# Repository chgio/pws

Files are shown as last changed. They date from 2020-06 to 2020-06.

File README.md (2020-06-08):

# PWS: Personal Weather Station software

##### COMPLETE HARDWARE-SOFTWARE-ASSEMBLY TUTORIAL ON [INSTRUCTABLES](https://www.instructables.com/id/Particle-Photon-IoT-Personal-Weather-Station)

##### SEE THE LIVE DATA PUBLISHED BY THIS CODE ON:
* [ThingSpeak](https://thingspeak.com/channels/920701)
* [WeatherUnderground](https://www.wunderground.com/dashboard/pws/IGENOA2776)
* [WeatherCloud](https://app.weathercloud.net/d0746983513#profile)

The PWS deployed
###### IMAGES ARE [CC BY 2.0](https://creativecommons.org/licenses/by/2.0)

## Hardware

Component                                           |Image                              | Store Link            | Documentation
---                                                 | ---                               | ---                   | ---
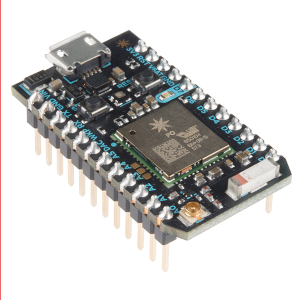
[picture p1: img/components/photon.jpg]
Photon
Particle Photon                                     |                      | [Particle Store][1b]  | [SparkFun Development Guide](https://learn.sparkfun.com/tutorials/photon-development-guide)
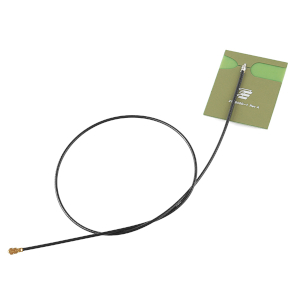
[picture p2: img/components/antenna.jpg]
Antenna
\[OPTIONAL\] 2.4GHz u.FL Antenna                    |                     | [SparkFun][2b]        | [SparkFun Hookup Guide](https://learn.sparkfun.com/tutorials/three-quick-tips-about-using-ufl)
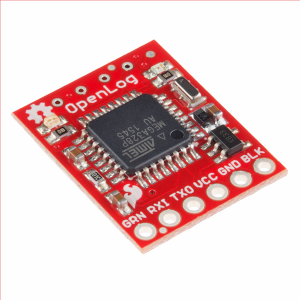
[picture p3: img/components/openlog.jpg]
OpenLog
SparkFun OpenLog                                    |                     | [SparkFun][3b]        | [SparkFun Hookup Guide](https://learn.sparkfun.com/tutorials/openlog-hookup-guide)
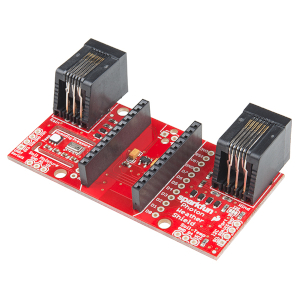
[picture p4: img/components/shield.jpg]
Weather Shield
SparkFun Photon Weather Shield                      |              | [SparkFun][4b]        | [SparkFun Hookup Guide](https://learn.sparkfun.com/tutorials/photon-weather-shield-hookup-guide-v11)
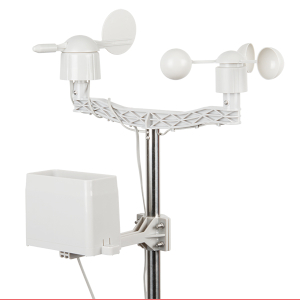
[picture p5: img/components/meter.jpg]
Weather Meters
SparkFun Weather Meters                             |              | [SparkFun][5b]        | [SparkFun Hookup Guide](https://learn.sparkfun.com/tutorials/weather-meter-hookup-guide)
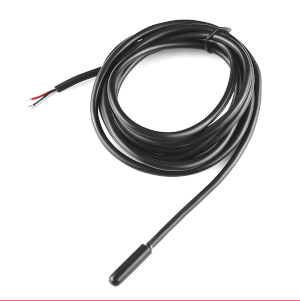
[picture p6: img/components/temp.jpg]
Soil Temperature Sensor
Dallas DS18B20 Waterproof Temperature Sensor        |     | [SparkFun][6b]        | [Example code by SparkFun on GitHub](https://github.com/sparkfun/simple_sketches/tree/master/DS18B20)
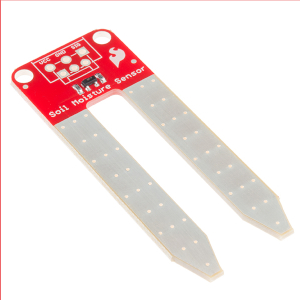
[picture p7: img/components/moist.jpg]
Soil Moisture Sensor
SparkFun Soil Moisture Sensor                       |        | [SparkFun][7b]        | [SparkFun Hookup Guide](https://learn.sparkfun.com/tutorials/soil-moisture-sensor-hookup-guide)
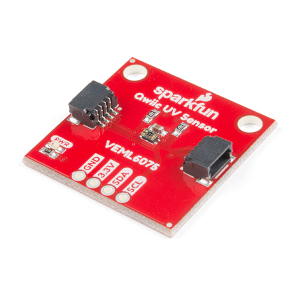
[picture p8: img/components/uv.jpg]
UV Sensor
SparkFun Qwiic VEML6075 UV Light Sensor Breakout    |                   | [SparkFun][8b]        | [SparkFun Hookup Guide](https://learn.sparkfun.com/tutorials/qwiic-uv-sensor-veml6075-hookup-guide)
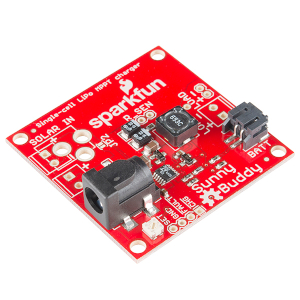
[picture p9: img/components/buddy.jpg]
Sunny Buddy
SparkFun Sunny Buddy                                |                 | [SparkFun][9b]        | [SparkFun Hookup Guide](https://learn.sparkfun.com/tutorials/qwiic-uv-sensor-veml6075-hookup-guide)
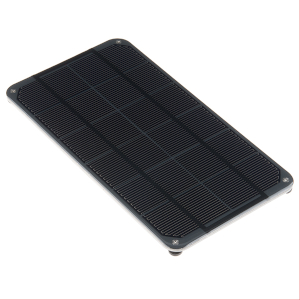
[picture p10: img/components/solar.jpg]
Solar Panel
3.5W solar panel                                    |                | [SparkFun][10b]       | --
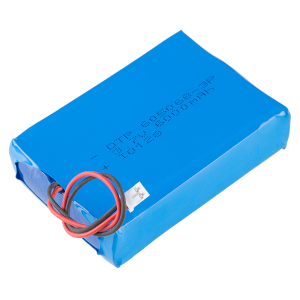
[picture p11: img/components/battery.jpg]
Li-Ion Battery
6Ah Li-Ion battery                                  |             | [SparkFun][11b]       | --
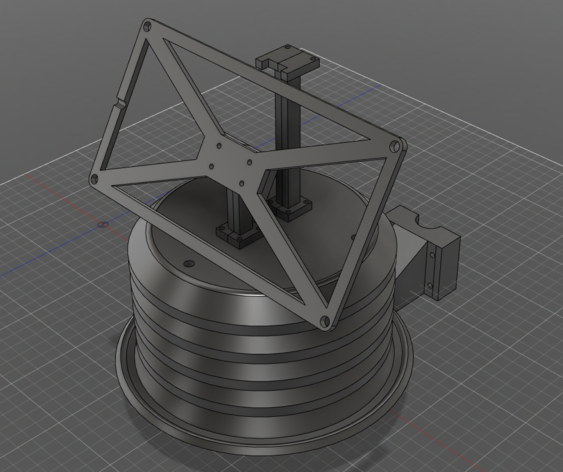
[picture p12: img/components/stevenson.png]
Stevenson Screen
Custom 3D Modelled Stevenson Screen                 |           | [Thingiverse][12b]    | --

[1a]:   
[1b]:   <https://store.particle.io/products/photon>
[2a]:   
[2b]:   <https://www.sparkfun.com/products/11320>   
[3a]:   
[3b]:   <https://www.sparkfun.com/products/>
[4a]:   
[4b]:   <https://www.sparkfun.com/products/13674>
[5a]:   
[5b]:   <https://www.sparkfun.com/products/15901>
[6a]:   
[6b]:   <https://www.sparkfun.com/products/11050>
[7a]:   
[7b]:   <https://www.sparkfun.com/products/13322>
[8a]:   
[8b]:   <https://www.sparkfun.com/products/15089>
[9a]:   
[9b]:   <https://www.sparkfun.com/products/12885>
[10a]:  
[10b]:  <https://www.sparkfun.com/products/13782>
[11a]:  
[11b]:  <https://www.sparkfun.com/products/13856>
[12a]:  
[12b]:  <https://www.thingiverse.com/thing:4435632>

## Setup

### Installation

Just clone or fork this repository from <https://github.com/ciakkig/pws>, and that's it.

#### Dependencies

Library                         | Download
---                             | ---
SparkFun Photon Weather Shield  | [GitHub][11]
OneWire                         | [GitHub][12]
Dallas DS18B20                  | [GitHub][13]
SparkFun VEML6075               | [GitHub][14]
ThingSpeak for Particle         | [GitHub][15]

[11]:   <https://github.com/sparkfun/SparkFun_Photon_Weather_Shield_Particle_Library>
[12]:   <https://github.com/particle-iot/OneWireLibrary>
[13]:   <https://github.com/particle-iot/SparkCoreDallasTemperature>
[14]:   <https://github.com/sparkfun/SparkFun_VEML6075_Arduino_Library>
[15]:   <https://github.com/mathworks/thingspeak-particle>

However, all required libraries are already included in the `lib` directory.

Additionally, this project was made using [Particle Workbench](https://www.particle.io/workbench) in [Visual Studio Code](https://code.visualstudio.com), and while not strictly necessary, using that is warmly recommended.

Otherwise, the code has also been styled (tabbed with 3 spaces) to be consistent with the [Particle Build](https://build.particle.io) cloud IDE, if that's more your thing.

### Registration

#### ThingSpeak

Set up a new channel on ThingSpeak [here](https://thingspeak.com/channels/new), entering your coordinates and elevation, and setting the first 7 fields to the following:
1. Temperature
2. Humidity
3. Pressure
4. UV Index
5. Rain Rate
6. Wind Speed
7. Wind Direction

Then, visit the channel's **API Keys** section and record your credentials to the `tsID` and `tsAPI` variables in the `credentials.h` file.

#### WeatherUnderground

Set up a personal weather station on WeatherUnderground [here](https://www.wunderground.com/member/devices/new), selecting "other" as hardware.     
You'll have to enter the station's location again, then record your credentials from the **Manage Devices** page to the `wuID` and `wuPASS` varaiables in the `credentials.h` file.

#### WeatherCloud

Set up a personal weather station on WeatherCloud [here](https://app.weathercloud.net/device/create), selecting "other" as model.   
Once again, you'll have to enter the station's location, but you'll be required to contact [WeatherCloud Support](mailto:support@weathercloud.net) to register your device to the API and get the necessary credentials -- but fear not, they don't have any particular requirements you need to satisfy.
You can then record your credentials to the `wcID`, `wcKEY` and `wcAPI`  variables in the `credentials.h` file.

For all the credentials mentioned in this section, feel free to use `templates/calibration_template.h` as a template, but don't forget to copy, rename and mention your file in your `.gitignore` if you're planning on redistributing the code to keep your credentials for yourself!

### Calibration

Calibrating sensors is always good practice.
However, the majority of the involved sensors already come factory-calibrated, and calibration methods at the intersection of reliability and affordability are basically non-existent.
Of course, you're free to calibrate as many sensors as you want -- just throw in some more `map()` functions -- but please let me know if you manage to find a good way.

As a requirement, however, you'll only have to run calibration on the sensor that needs it the most: the soil moisture sensor.      
To do that, as shown in [SparkFun's Hookup Guide](https://learn.sparkfun.com/tutorials/soil-moisture-sensor-hookup-guide#calibration), put it about three-quarters of its way inside the soil you want to calibrate it for, in a completely dry condition, and record this first raw reading to the `smCal0` variable.
Then, wet the soil as much as you can, until it's saturated with water, and record this second raw reading to the `smCal100` variable.  
Don't worry if the two values happen to be quite close: I had a difference of about **300** -- **9%** of my maximum value, and a mere tenth of the difference between my minimum value and the actual 0 recorded in air.

Another element that requires calibration is the Sunny Buddy: while not a sensor, its MPPT (Maximum Power Point Transfer) design needs to be calibrated to that point of maximum power transfer.    
To do that, as once again shown in [SparkFun's Hookup Guide](https://learn.sparkfun.com/tutorials/sunny-buddy-solar-charger-v13-hookup-guide), connect it to your solar panel on a sunny day, measure the voltage across the `SET` and `GND` pads, and tweak the nearby potentiometer with a screwdriver until that voltage is about **3V.**

## Usage

### Compiling & Flashing

#### Local

* Local compile the project through the Workbench shortcut
* Flash the compiled project over-the-wire through the Workbench shortcut

#### Cloud

* Cloud compile the project with `particle compile photon`
* Flash the compiled project over-the-air with `particle flash pws pws.bin`

I usually prefer to compile locally for more reliability and control over the code, then flash it over the air for a seamless update from wherever I happen to be.

### Interaction

The [Particle Cloud API](https://docs.particle.io/reference/device-cloud/api) provides a number of useful tools to interface with the Photon through [Particle's CLI](https://docs.particle.io/reference/developer-tools/cli/).     
Mainly, the use of [Particle Variables](https://docs.particle.io/reference/device-os/firmware/photon/#particle-variable), [Particle Functions](https://docs.particle.io/reference/device-os/firmware/photon/#particle-function) and [Particle Events](https://docs.particle.io/reference/device-os/firmware/photon/#particle-publish).

You can `get` a variable's value by issuing:    
```particle get var```      
For example, to get the `soilMoisture` variable:    
```particle get soilMoisture```

You can also `call` a function with:    
```particle call device function argument```    
For example, to call the `setSleepAt0` function with argument `0` on your device `pws`:     
```particle call pws setSleepAt0 0```

Here's the full list of all variables and functions (with their syntax) exposed through the Particle Cloud API:

Variable            | Unit
---                 | ---
`temperature`       | °C
`humidity`          | Pa
`pressure`          | %
`soilTemperature`   | °C
`soilMoisture`      | %
`uv`                | -- (index)
`rain`              | mm/min
`windSpeed`         | km/h
`windDirection`     | °N

Function                    | Arguments                                 | Usage                                                                                                                                                                 | Returns
---                         | ---                                       | ---                                                               | ---
`gotoSleepNow`              | `seconds`: > 0 / none for default         | Sends the Photon into deep sleep immediately for the specified `seconds`. If no value is specified, the code-defined default (currently 300) is used.                     | Nothing, as the Photon will be fast asleep.
`setSleepAt0`               | `flag`: 0 ~ 1                             | Overrides the flag that determines whether the Photon enters deep sleep or stays awake at the end of the loop.                                                            | 2-digit integer: *`ON`*, made up of the *O*ld flag and *N*ew flag.
`setSampleSeconds`          | `seconds`: 1 ~ 300                        | Overrides the value that determines how long the Photon samples the sensors for. If no value is specified, the code-defined default (currently 60) is used as a reset.    | 6-digit integer: *`OLDNEW`*, made up of *OLD* time and *NEW* time. `-1` in case of invalid arguments.
`getWeather`                | `seconds`: 1 ~ 300 / none for default     | Polls all sensors for the current weather, sampling in loop for the specified `seconds`. If no value is specified, the code-defined default (currently 60) is used.       | 8-digit integer: *`TEHUPRES`*, made up of *TE*mperature, *HU*midity and *PRES*sure. `-1` in case of invalid arguments.
`printData`                 | --                                        | Prints the weather data over USB Serial to a PC.                                                                                                                          | `1` in case of success, `-1` in case of failed Serial connection.
`logData`                   | --                                        | Logs the weather data over RX-TX Serial to the OpenLog.                                                                                                                   | `1` in case of success, `-1` in case of failed Serial connection.
`publishData`               | --                                        | Publishes the weather data to the Particle Cloud as private Events.                                                                                                       | `1` in case of success, nothing or error in case of failed Cloud connection.
`publishThingSpeak`         | --                                        | Publishes the weather data to [ThingSpeak](https://thingspeak.com).                                                                                                       | `1` in case of success, nothing or error in case of failed Internet connection.
`publishWeatherUnderground` | --                                        | Publishes the weather data to [WeatherUnderground](https://weatherunderground.com).                                                                                       | `1` in case of success, nothing or error in case of failed Internet connection.
`publishWeatherCloud`       | --                                        | Publishes the weather data to [WeatherCloud](https://weathercloud.net).                                                                                                   | `1` in case of success, nothing or error in case of failed Internet connection.

## Operating Principles

This program focuses on robustness, debugability and power efficiency on remote deployment, while slightly overlooking the already relatively limited precision introduced by the general-purpose sensors on board. Rather, this is expected to be achieved through a bigger set of data, both through a long, frequent and constant gathering and by averaging a number of samples to measure such data.

By default, the weather station will:
* wake up at every **--:-5** minute (i.e. 10:05, 10:15, 10:25, etc.)
* take measurements for each quantity
* do the necessary computations on the measurements
* post the data to the Particle Cloud and to the various weather network websites
* send its sensors to sleep to lower power consumption
* stand by for the next 4-5 minutes to offer a practical window for troubleshooting
* enter deep sleep at every **--:-0** minute (i.e. 10:10, 10:20, 10:30, etc.)
* repeat

However, this default cycle can be easily tailored to any particular need for troubleshooting or power saving using the interfaces mentioned above.

## License

**Copyright (C) 2020 Giorgio Ciacchella**

This program is free software: you can redistribute it and/or modify it under the terms of the GNU General Public License as published by the Free Software Foundation, either version 3 of the License, or (at your option) any later version.

This program is distributed in the hope that it will be useful, but WITHOUT ANY WARRANTY; without even the implied warranty of MERCHANTABILITY or FITNESS FOR A PARTICULAR PURPOSE.

See the GNU General Public License at `COPYING` or <https://www.gnu.org/licenses/#GPL> for more details.

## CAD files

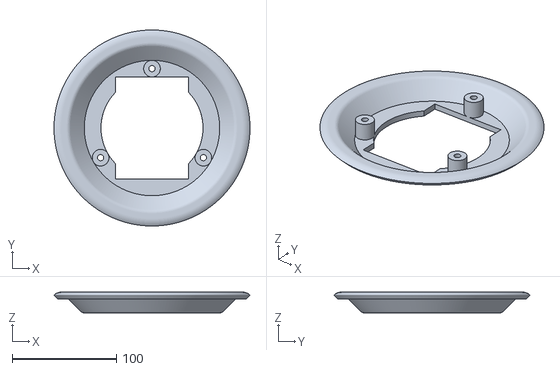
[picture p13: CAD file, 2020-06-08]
stl/screen1.stl
188.3 x 188.3 x 20.0

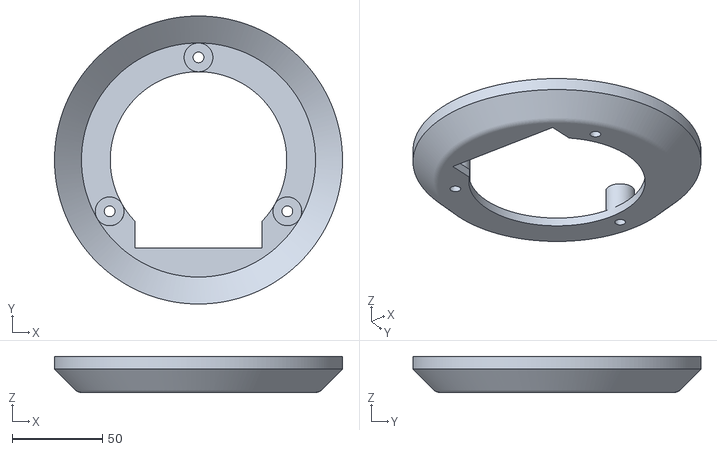
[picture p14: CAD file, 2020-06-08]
stl/screen2.stl
160.0 x 160.0 x 20.0

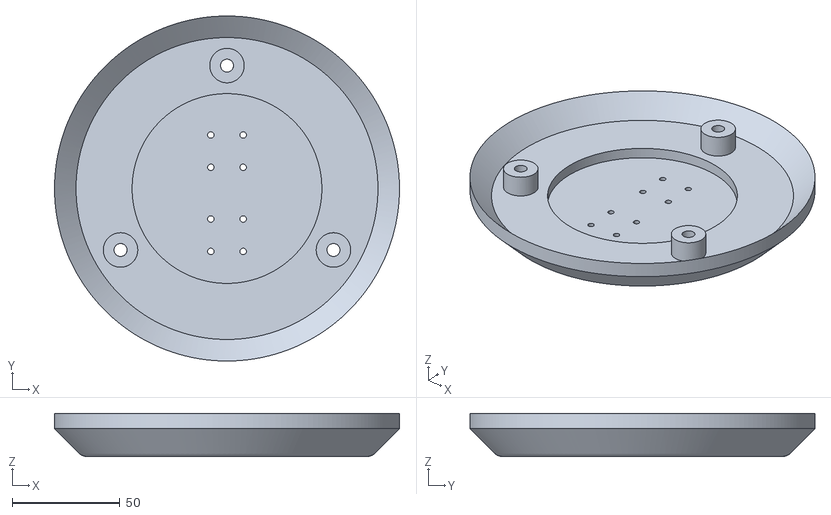
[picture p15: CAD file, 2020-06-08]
stl/screen5.stl
160.0 x 160.0 x 20.0

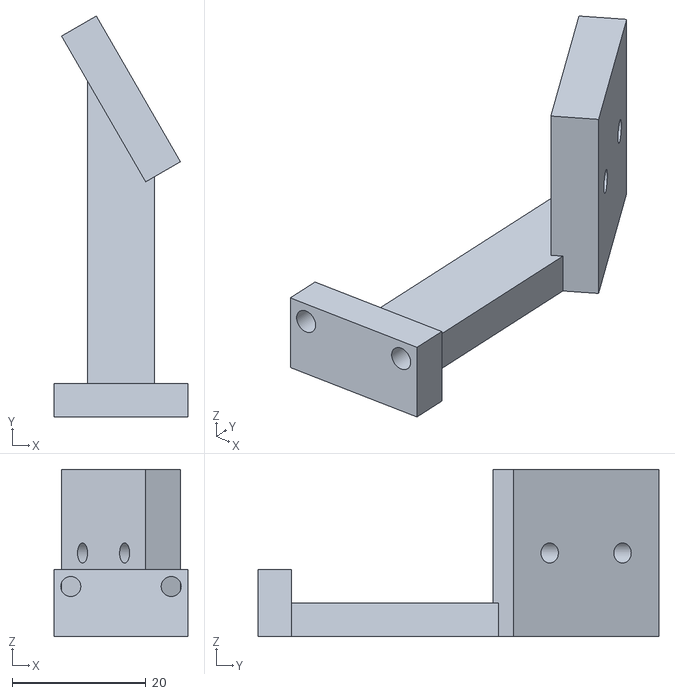
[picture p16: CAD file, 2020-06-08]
stl/solarPanelHolderLeft.stl
20.0 x 59.9 x 25.0

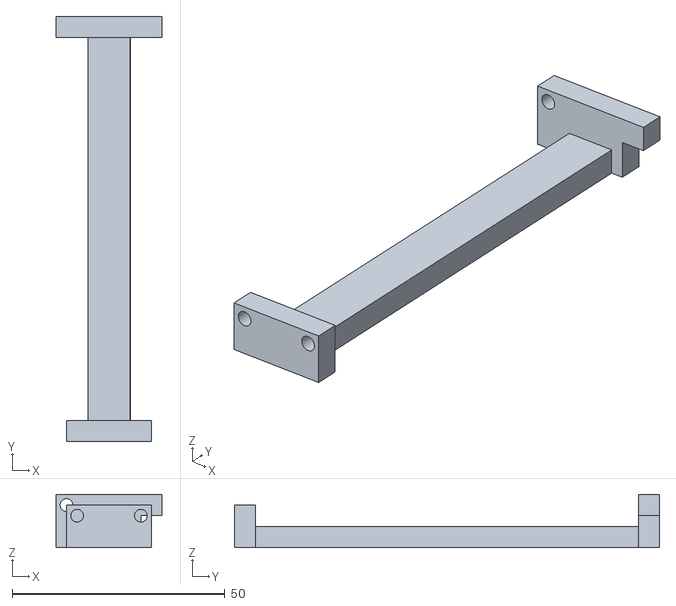
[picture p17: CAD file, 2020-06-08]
stl/uvHolderLeft.stl
25.0 x 100.0 x 12.5

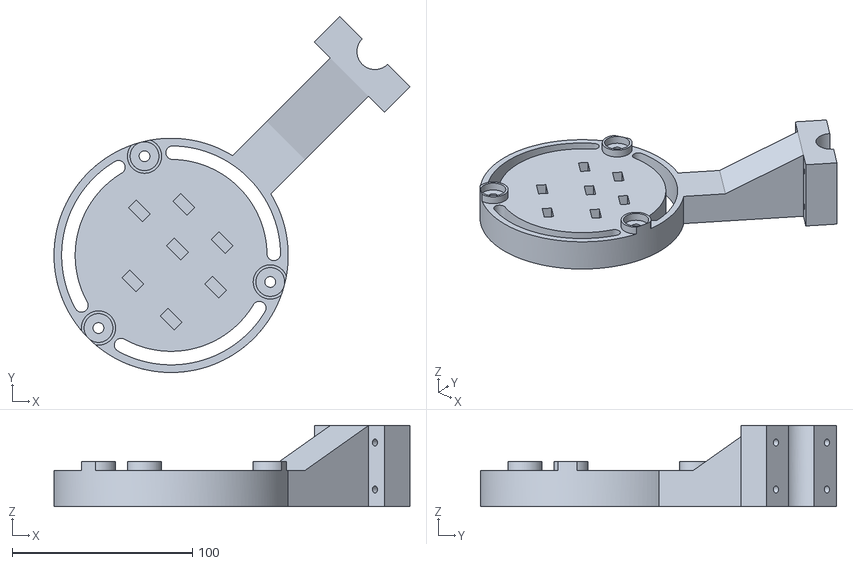
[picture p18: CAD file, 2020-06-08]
stl/basePiece.stl
197.6 x 197.6 x 45.0

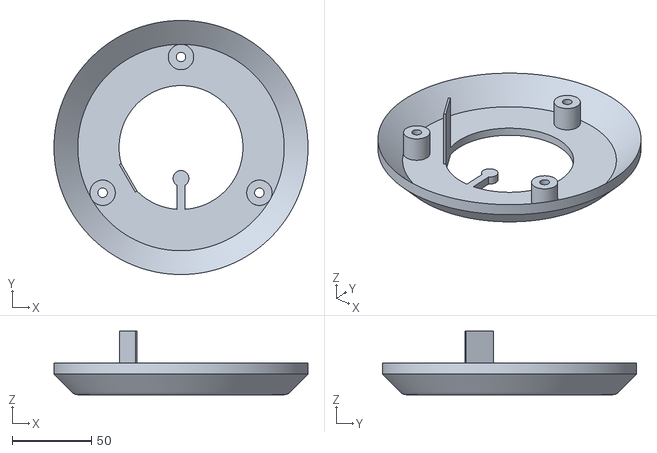
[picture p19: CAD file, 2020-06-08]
stl/screen3.stl
160.0 x 160.0 x 40.0

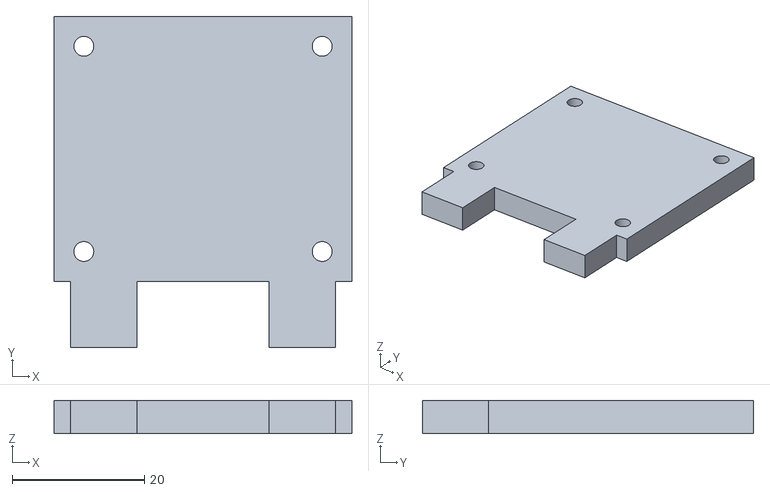
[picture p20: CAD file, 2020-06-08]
stl/shieldPiece.stl
45.0 x 50.0 x 5.00

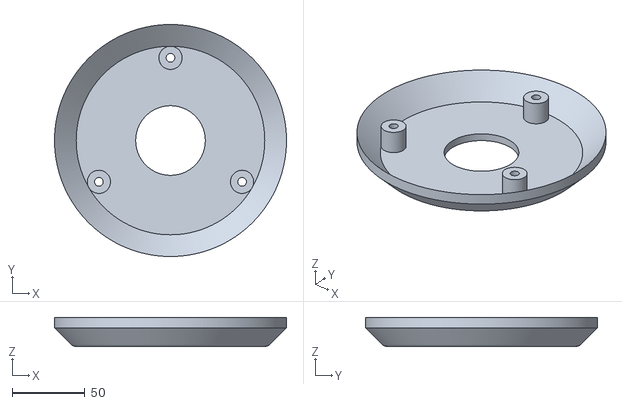
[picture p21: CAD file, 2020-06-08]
stl/screen4.stl
160.0 x 160.0 x 20.0

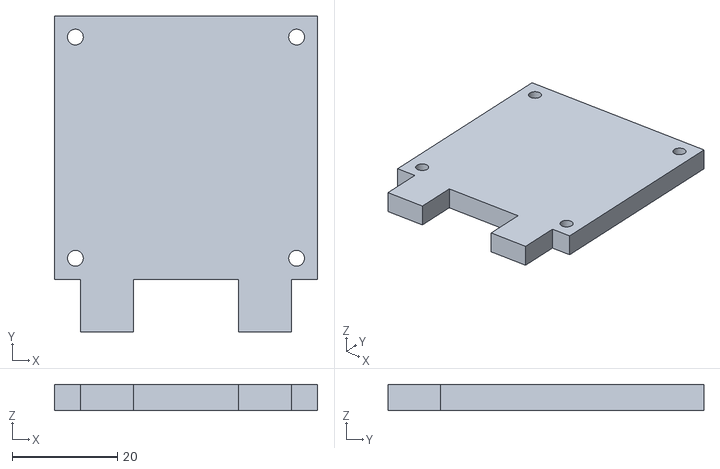
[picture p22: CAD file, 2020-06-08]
stl/sunPiece.stl
50.0 x 60.0 x 5.00

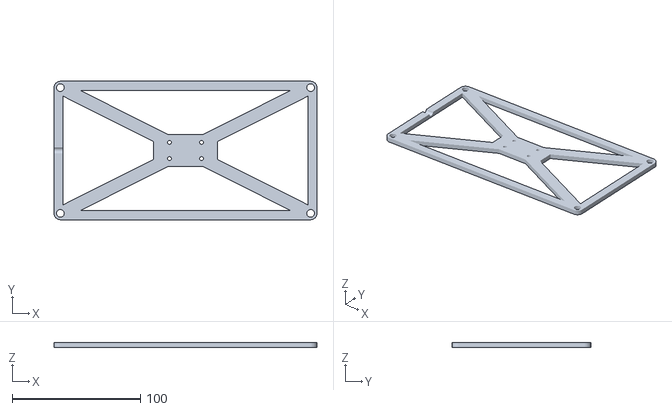
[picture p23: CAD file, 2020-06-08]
stl/solarPanelRack.stl
205.0 x 108.0 x 4.00

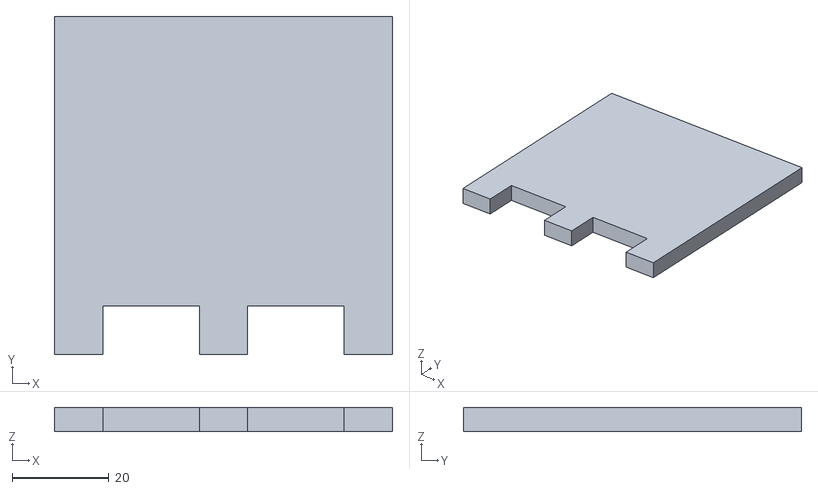
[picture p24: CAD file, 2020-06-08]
stl/batteryPiece.stl
70.0 x 70.0 x 5.00

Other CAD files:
stl/solarPanelHolderRight.stl
stl/uvHolderRight.stl

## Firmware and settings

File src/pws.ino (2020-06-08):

/*

* pws.ino         [Particle-flavoured C++]
   full version: implements all sensors and meters
   check the "simplified" git branch for the simplified version
   only implementing the Photon Weather Shield


* Description:    Particle Photon Personal Weather Station software
                  dedicated to collecting, processing and uploading the data


* Author:         Giorgio Ciacchella (https://github.com/ciakkig)


* License:        GNU GPLv3 license
   Copyright (C) 2020 Giorgio Ciacchella

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

* Hardware:
   Particle Photon                                    https://store.particle.io/products/photon
   [OPTIONAL] 2.4GHz u.FL antenna                     https://www.sparkfun.com/products/11320
   SparkFun OpenLog                                   https://www.sparkfun.com/products/13712

   SparkFun Photon Weather Shield                     https://www.sparkfun.com/products/13674
   SparkFun Weather Meters                            https://www.sparkfun.com/products/15901
   Dallas DS18B20 Waterproof Temperature Sensor       https://www.sparkfun.com/products/11050
   SparkFun Soil Moisture Sensor                      https://www.sparkfun.com/products/13322
   SparkFun Qwiic VEML6075 UV Light Sensor            https://www.sparkfun.com/products/15089

   3.5W solar panel                                   https://www.sparkfun.com/products/13782
   SparkFun Sunny Buddy                               https://www.sparkfun.com/products/12885
   Custom 3D Modelled Stevenson Screen                https://www.thingiverse.com/thing:4435632


* Creation:       04/2017
   Latest Update: 06/2020


*/


#include <math.h>

#include <SparkFun_Photon_Weather_Shield_Library.h>
#include <OneWire.h>
#include <spark-dallas-temperature.h>
#include <SparkFun_VEML6075.h>
#include <ThingSpeak.h>

#include <calibration.h>
#include <credentials.h>


Weather shield;
OneWire oneWire(D4);
DallasTemperature thermo(&oneWire);
VEML6075 uv;
ThingSpeakClass ts;
TCPClient client;


//===========================================================
// DECLARATIONS
//===========================================================

int sleepAt0 = 1;                   // default flag to determine wheter the Photon goes to sleep at the end of the loop or stays awake
long sampleSecondsDefault = 60;     // default seconds spent by getWeather() in the sampling loop, when not overridden by getWeather()'s argument

double temperatureC;
double humidityRH;
double pressurePa;
double uvIndex;
double soilTemperatureC;
double soilMoistureRH;

double rainMmMin;
double windSpeedKMH;
double windDirection;

double dewPointC;
double heatIndexC;
double windChillC;

volatile unsigned int lastRainClick;
volatile unsigned int totalRainClicks;

volatile unsigned int lastWindClick;
volatile unsigned int totalWindClicks;

SYSTEM_MODE(SEMI_AUTOMATIC);                    // Particle system mode override: semi-automatic for manual control over connection to the cloud
                                                // but automatic processing once that's done
                                                // <https://docs.particle.io/reference/device-os/firmware/photon/#system-modes>

// Particle cloud functions: must be declared before setup, return int and take one String
uint32_t getWeather(String arg);                // returns unsigned, 32-bit integer for weather data at a glance
int logData(String arg);
int publishData(String arg);
int publishThingSpeak(String arg);
int publishWeatherUnderground(String arg);
int publishWeatherCloud(String arg);


//===========================================================
// ROUTINE
//===========================================================

void setup()
{
   STARTUP(WiFi.selectAntenna(ANT_EXTERNAL));   // make sure the external antenna is engaged
                                                // comment it out or edit to ANT_INTERNAL
                                                //  if you're not using an external u.FL antenna

   Time.zone(1);                                // edit this according to your timezone
   Time.beginDST();                             // comment one of these two out and leave the other insampleMillis
   Time.endDST();                               // depending on what time of the year you flash the code
   
   Particle.function("gotoSleepNow", gotoSleepNow);
   Particle.function("setSleepAt0", setSleepAt0);
   Particle.function("setSampleSeconds", setSampleSeconds);
   Particle.function("getWeather", getWeather);
   Particle.function("logData", logData);
   Particle.function("publishData", publishData);
   Particle.function("publishThingSpeak", publishThingSpeak);
   Particle.function("publishWeatherUnderground", publishWeatherUnderground);
   Particle.function("publishWeatherCloud", publishWeatherCloud);
   Particle.connect();

   initialiseWeatherShield();
   initialiseRainGauge();
   initialiseAnemometer();
   initialiseParticleVariables();

   Serial.begin(9600);                          // USB serial interface to PC
   Serial1.begin(9600);                         // RX-TX serial interface the OpenLog
   ThingSpeak.begin(client);
   delay(1000);                                 // one-second delay to allow sensor, serial and remote interfaces to connect safely
   Serial.printlnf("%s: Setup Completed.", Time.timeStr());
   Serial.print("\r\n\r\n");
}

void loop()
{
   if (sleepAt0 && Time.minute() % 10 == 0)     // once per 10 minutes, at every --:-0 minute
   {
      System.sleep(SLEEP_MODE_DEEP, 300);
   }
   
   if (Time.minute() % 5 == 0)                  // once per 10 minutes, at every --:-5 minute
   {
      getWeather("");
      logData("");

      Particle.connect();

      if (Particle.connected())
      {
         publishData("");
         publishThingSpeak("");
         publishWeatherUnderground("");
         publishWeatherCloud("");
      }

      if (Time.hour() == 0 && Time.day() == 28 && Time.month() == 10)
      {
         Time.beginDST();
      }
      if (Time.hour() == 0 && Time.day() == 31 && Time.month() == 3)
      {
         Time.endDST();
      }
   }
}


//===========================================================
// INITIALISATION
//===========================================================

void initialiseWeatherShield()
{
   shield.begin();
   shield.heaterOff();                          // make sure the Si7021 heater is turned off by default
   shield.setModeBarometer();                   // set MPL3115A2 mode to barometer rather than altimeter
   shield.setOversampleRate(7);                 // sets the time between the different sub-samples to the maximum
   shield.enableEventFlags();                   // enable the registers to get the data

   uv.begin();
   uv.setIntegrationTime(VEML6075::IT_200MS);   //
   uv.setHighDynamic(VEML6075::DYNAMIC_HIGH);   //

   pinMode(D5, OUTPUT);                         // soil moisture sensor power pin
   pinMode(A1, INPUT);                          // soil moisture sensor data pin
}

void initialiseRainGauge()
{
   pinMode(D2, INPUT_PULLUP);
   attachInterrupt(D2, handleRainClick, FALLING);
   lastRainClick = 0;
}

void initialiseAnemometer()
{
   pinMode(D3, INPUT_PULLUP);
   attachInterrupt(D3, handleWindClick, FALLING);
   lastWindClick = 0;
}

void initialiseParticleVariables()
{
   Particle.variable("temperature", temperatureC);
   Particle.variable("humidity", humidityRH);
   Particle.variable("pressure", pressurePa);
   Particle.variable("soilTemperature", soilTemperatureC);
   Particle.variable("soilMoisture", soilMoistureRH);
   Particle.variable("uv", uvIndex);
   Particle.variable("rain", rainMmMin);
   Particle.variable("windSpeed", windSpeedKMH);
   Particle.variable("windDirection", windDirection);
}


//===========================================================
// INTERFACEABLE MODIFIERS
//===========================================================

int gotoSleepNow(String arg)                             // sends the Photon into deep sleep for the specified duration in seconds
{  
   int duration;

   if (arg == "")
   {
      duration = 300;
   }
   else
   {
      duration = arg.toInt();
      if (duration < 0)
      {
         return -1;                                      // returns -1 in case of invalid argument
      }
      else
      {
         System.sleep(SLEEP_MODE_DEEP, duration);
         return 1;                                       // won't return anything in case of success, as the Photon will be sleeping
      }  
   }
}

int setSleepAt0(String arg)                              // overrides the flag that determines whether the Photon goes to sleep or stays awake at the end of the loop
{
   int oldFlag = sleepAt0;
   int newFlag = arg.toInt();

   if (newFlag == 0 || newFlag == 1)
   {
      sleepAt0 = newFlag;
      return oldFlag * 10 + sleepAt0;                    // returns a 2-digit confirmation integer made up of the previous flag followed by the new flag
   }
   else
   {
      return -1;                                         // or the conventional -1 in case of invalid argument
   }
}

int setSampleSeconds(String arg)                         // overrides the default sample loop duration
{
   int oldSeconds = sampleSecondsDefault;
   int newSeconds;
   if (arg == "")
   {
      newSeconds = sampleSecondsDefault;
   }
   else
   {
      newSeconds = arg.toInt();
      if (newSeconds < 1 || newSeconds > 300)
      {
      return -1;                                         // returns -1 for too long a duration
      }
      else
      {
      return oldSeconds * 100 + sampleSecondsDefault;    // or a confirmation number made up of the previous time followed by the new time
      }
   }
}

//===========================================================
// MAIN WEATHER FUNCTION
//===========================================================

uint32_t getWeather(String sampleSecondsArg)    // needs to return unsigned, 32-bit integer for weather data at a glance:
{                                               // the TE-HU-PRES return format is safe from overflowing even with Farenheit temperatures
   uint64_t sampleMillis;                       // calling Particle's System.millis() allows for a 64-bit value instead of the standard 32-bit value 
   int sampleSeconds;
   if (sampleSecondsArg == "")
   {
      sampleMillis = sampleSecondsDefault * 1000;
   }
   else 
   {
      sampleSeconds = sampleSecondsArg.toInt();
      if (sampleSeconds < 1 || sampleSeconds > 300)
      {
         return -1;
      }
      else
      {
         sampleMillis = sampleSeconds * 1000;
      }
   }
   
   double totalTemperatureC = 0;
   double totalHumidityRH = 0;
   double totalPressurePa = 0;
   double totalSoilTemperatureC = 0;
   int totalSoilMoistureRaw = 0;
   double totalUvIndex = 0;

   totalRainClicks = 0;
   totalWindClicks = 0;
   double totalWindSin = 0;
   double totalWindCos = 0;

   // set the shield and sensors up for measurement
   shield.setModeActive();
   digitalWrite(D5, HIGH);
   uv.powerOn();
   delay(100);

   bool shieldHeaterOnFlag = false;                
   double humidityDiscriminant = shield.getRH();   // a decisive humidity reading is taken immediately
                                                   // so that the Si7021 heater can be turned on in case of extreme moisture
   if (humidityDiscriminant >= 90)
   {
      shieldHeaterOnFlag = true;
      shield.heaterOn();
   }
   else
   {
      shield.heaterOff();
   }
   delay(250);
   
   unsigned int sampleCount = 0;
   uint64_t startMillis = System.millis();
   uint64_t endMillis = startMillis + sampleMillis;

   // start the sampling loop
   while (System.millis() < endMillis)
   {
      if (shieldHeaterOnFlag)
      {
         totalTemperatureC += shield.readBaroTemp();  // if that's the case, read the temperature from the alternative MPL3115A2 sensor
                                                      // to prevent the heater' from affecting the measurement
      }
      else
      {
         totalTemperatureC += shield.readTemp();      // otherwise, read the temperature from the usual Si702 sensor
                                                      // since the turned off heater has no effect anyway
      }
      totalHumidityRH += shield.getRH();
      delay(50);

      totalPressurePa += shield.readPressure() / 100;
      delay(50);
      
      // soil temperature
      thermo.requestTemperatures();
      delay(50);
      totalSoilTemperatureC += thermo.getTempCByIndex(0);

      // soil moisture
      totalSoilMoistureRaw += analogRead(A1);
      delay(50);

      // uv
      totalUvIndex += uv.index();
      delay(50);

      // wind vane
      double windRaw = analogRead(A0);
      delay(50);
      double windRadians = lookupRadiansFromRaw(windRaw);
      totalWindSin += sin(windRadians);
      totalWindCos += cos(windRadians);

      sampleCount++;
      delay(100);      
   }

   // send the shield and sensors to standby
   shield.setModeStandby();
   digitalWrite(D5, LOW);
   uv.shutdown();

   // compute the average values 
   temperatureC = totalTemperatureC / sampleCount;
   humidityRH = totalHumidityRH / sampleCount;
   pressurePa = totalPressurePa / sampleCount;
   uvIndex = totalUvIndex / sampleCount;
   soilTemperatureC = totalSoilTemperatureC / sampleCount;
   int soilMoistureRaw = totalSoilMoistureRaw / sampleCount;
   soilMoistureRH = double(map(soilMoistureRaw, smCal0, smCal100, 0, 100));   // convert the soil moisture raw reading to relative humidity percentile
                                                                              // according to the calibration values

   // get the values from the interrupt sensor clicks
   rainMmMin = getRain(totalRainClicks, sampleMillis);
   windSpeedKMH = getWindSpeed(totalWindClicks, sampleMillis);
   windDirection = getWindDirection(totalWindSin / sampleCount, totalWindCos / sampleCount);

   // compute the secondary quantities
   dewPointC = dewPoint(temperatureC, humidityRH);
   heatIndexC = toC(heatIndex(toF(temperatureC), humidityRH));
   windChillC = toC(windChill(toF(temperatureC), toMPH(windSpeedKMH)));

   // return data in the TE-HU-PRES format (TEmperature, HUmidity, PRESsure)
   // to have all the basic weather data at a glance as Particle cloud response
   return uint32_t(int(temperatureC)*pow(10, 6)) + uint32_t(int(humidityRH)*pow(10, 4)) + uint32_t(int(pressurePa));
}


//===========================================================
// RAIN GAUGE
//===========================================================

void handleRainClick()
{
   if (System.millis() - lastRainClick > 10) // ignore switch-bounce glitches less than 10ms after initial edge
   {
      totalRainClicks++;
      lastRainClick = System.millis();       // set up for the next click
   }
}

double getRain(int rainClicks, long sampleTimeMillis)
{  
   double sampleTimeMinutes = sampleTimeMillis / 60000;
   double rainMmMin = 0.2794 * rainClicks / sampleTimeMinutes;

   return rainMmMin;
}


//===========================================================================
// ANEMOMETER
//===========================================================================

void handleWindClick()
{
   if (System.millis() - lastWindClick > 10) // ignore switch-bounce glitches less than 10ms after initial edge
   {
      totalWindClicks++;
      lastWindClick = System.millis();       // set up for the next click
   }
}

double getWindSpeed(int windClicks, long sampleTimeMillis)
{
   double sampleTimeSeconds = sampleTimeMillis / 1000;
   double windSpeedKMH = 2.4 * windClicks / sampleTimeSeconds;
   
   return windSpeedKMH;
}


//===========================================================
// WIND VANE
//===========================================================

double getWindDirection(double windSin, double windCos)
{
   double result = atan(windSin/windCos) * 180.0 / M_PI;

   // atan can only tell where the angle is within 180 degrees. Need to look at cos to tell which half of circle we're in
   if (windCos < 0)
   {
      result += 180.0;
   }
   // atan will return negative angles in the NW quadrant -- push those into positive space.
   if (result < 0)
   {
      result += 360.0;
   }
   windDirection = result;
}

double lookupRadiansFromRaw(unsigned int analogRaw)
{
   if (analogRaw >= 2200 && analogRaw < 2400) return (3.14);   // South
   if (analogRaw >= 2100 && analogRaw < 2200) return (3.53);   // SSW
   if (analogRaw >= 3200 && analogRaw < 3299) return (3.93);   // SW
   if (analogRaw >= 3100 && analogRaw < 3200) return (4.32);   // WSW
   if (analogRaw >= 3890 && analogRaw < 3999) return (4.71);   // West
   if (analogRaw >= 3700 && analogRaw < 3780) return (5.11);   // WNW
   if (analogRaw >= 3780 && analogRaw < 3890) return (5.50);   // NW
   if (analogRaw >= 3400 && analogRaw < 3500) return (5.89);   // NNW
   if (analogRaw >= 3570 && analogRaw < 3700) return (0.00);   // North
   if (analogRaw >= 2600 && analogRaw < 2700) return (0.39);   // NNE
   if (analogRaw >= 2750 && analogRaw < 2850) return (0.79);   // NE
   if (analogRaw >= 1510 && analogRaw < 1580) return (1.18);   // ENE
   if (analogRaw >= 1580 && analogRaw < 1650) return (1.57);   // East
   if (analogRaw >= 1470 && analogRaw < 1510) return (1.96);   // ESE
   if (analogRaw >= 1900 && analogRaw < 2000) return (2.36);   // SE
   if (analogRaw >= 1700 && analogRaw < 1750) return (2.74);   // SSE
}


//===========================================================
// DATA OUTPUT
//===========================================================

// Serial Print to PC
int printData(String arg)
{
   Serial.println(Time.timeStr());
   Serial.printlnf("Temperature:\t%f °C", temperatureC);
   Serial.printlnf("Humidity:\t%f \%", humidityRH);
   Serial.printlnf("Pressure:\t%f Pa", pressurePa);
   Serial.printlnf("UV Index:\t%f", uvIndex);
   Serial.printlnf("Soil Temperature:\t%f °C", soilTemperatureC);
   Serial.printlnf("Soil Moisture:\t%f \%", soilMoistureRH);
   Serial.printlnf("Rain Rate:\t%f mm/min", rainMmMin);
   Serial.printlnf("Wind Speed:\t%f km/h", windSpeedKMH);
   Serial.printlnf("Wind Direction:\t%f °N", windDirection);
   Serial.print("\r\n\r\n");

   return 1;
}

// Serial Log to OpenLog
int logData(String arg)
{
   if (Serial1.available() && Serial1.read() == '<')
   {
      // log the data in CSV format as:
      // unixtime, temp, hum, press, uv, soiltemp, soilmoist, rainrate, windspeed, winddir
      Serial1.print(Time.now());
      Serial1.printf("%s,", Time.timeStr());
      Serial1.printf("%f,", temperatureC);
      Serial1.printf("%f,", humidityRH);
      Serial1.printf("%f,", pressurePa);
      Serial1.printf("%f,", uvIndex);
      Serial1.printf("%f,", soilTemperatureC);
      Serial1.printf("%f,", soilMoistureRH);
      Serial1.printf("%f,", rainMmMin);
      Serial1.printf("%f,", windSpeedKMH);
      Serial1.printlnf("%f", windDirection);

      return 1;
   }
   else
   {
      return -1;
   }
   
}

// Particle Console
int publishData(String arg)
{
   Particle.publish("temperature", String(temperatureC), PRIVATE);
   delay(100);
   Particle.publish("humidity", String(humidityRH), PRIVATE);
   delay(100);
   Particle.publish("pressure", String(pressurePa), PRIVATE);
   delay(100);
   Particle.publish("uvIndex", String(uvIndex), PRIVATE);
   delay(100);
   Particle.publish("soilTemperature", String(soilTemperatureC), PRIVATE);
   delay(100);
   Particle.publish("soilMoisture", String(soilMoistureRH), PRIVATE);
   delay(100);
   Particle.publish("rain", String(rainMmMin), PRIVATE);
   delay(100);
   Particle.publish("windSpeed", String(windSpeedKMH), PRIVATE);
   delay(100);
   Particle.publish("windDirection", String(windDirection), PRIVATE);
   delay(100);

   return 1;
}

// ThingSpeak
int publishThingSpeak(String arg)
{
   ThingSpeak.setField(1, float(temperatureC));
   ThingSpeak.setField(2, float(humidityRH));
   ThingSpeak.setField(3, float(pressurePa));
   ThingSpeak.setField(4, float(uvIndex));
   ThingSpeak.setField(5, float(rainMmMin));
   ThingSpeak.setField(6, float(windSpeedKMH));
   ThingSpeak.setField(7, float(windDirection));
   delay(100);
   ThingSpeak.writeFields(tsID, tsAPI);

   return 1;
}
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

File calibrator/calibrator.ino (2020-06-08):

// calibrator.ino
// helper software to record the calibration readings
// and print them out through serial for calibration.h


long soilMoisture;
long soilMoistureTot;
long soilMoistureN;
long soilMoistureAvg;

void setup()
{
   pinMode(D5, OUTPUT);    // soil moisture sensor power pin
   pinMode(A1, INPUT);     // soil moisture sensor data pin
   
   delay(1000);

   Serial.begin(9600);
}

void loop()
{
   /* Soil moisture: place the sensor
   about 3/4 of its way inside the target soil, manipulate its moisture
   and record the readings:
   * completely dry soil:              0        %RH
   * completely wet soil:              100      %RH
   */

   digitalWrite(D5 , HIGH);
   delay(250);

   soilMoisture = analogRead(A1);
   delay(250);
   
   digitalWrite(D5, LOW);
   delay(250);

   soilMoistureTot += soilMoisture;
   soilMoistureN++;
   soilMoistureAvg = soilMoistureTot / soilMoistureN;

   Serial.printlnf("\tSoil Moist: %d\tRunning Avg: %d", soilMoisture, soilMoistureAvg);

   delay(1500);
}

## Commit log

2020-06-08 cleaned up stl dir
    [basePiece.stl, batteryPiece.stl, screen1.stl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]
2020-06-08 fresh weather network devices
